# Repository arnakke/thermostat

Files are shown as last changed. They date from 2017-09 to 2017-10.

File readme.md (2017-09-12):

Intelligent Thermostat
----------------------
The thermostat should control room temperature based on the time of day and the location of residents. Thermostats will be connected together in rooms and homes, so if a room has multiple radiators, they will all have the same temperature set point, and if all residents have left the home, the temperature in all rooms will be lowered. Whether residents are home will be determined based on the location of their smartphones. 
Rooms should be able to have different temperatures during day and night, so that eg. the temperature is lowered in the living room during night and in the bedroom during day.  
The goal is a “set and forget” device, meaning that ideally you will never have to touch the app or the thermostats after initial configuration. That means it should also include air out detection, to stop heating when windows or doors are open. This detection could be augmented by utilizing outdoor temperature measurements from an online weather service.  
The device might also include a photovoltaic cell (or alternatively a peltier element) to reduce or eliminate battery changes.  
The design philosophy is to have as simple a user experience as possible. The thermostat should be easily installable and simple to configure, with no central control unit.

While there are a lot of similar products in the market, this thermostat sets itself apart by having:
* Centralized control without a central control unit
* Potentially a much lower price point than comparable systems (low price bill of materials)
* A design goal of being simple, unintrusive and “set and forget” (in contrast to big control panels, painful programming, manually turning on/off remotely and similar features)
* Open software and hardware design

### Preliminary requirements:
1. Thermostat unit should be mountable on Danfoss type  RA radiator valve
2. Thermostat unit should be able to partially open the radiator valve in at least 20 steps
3. Thermostat unit should be able to completely close the radiator valve
4. Thermostat unit should be able to measure temperature in a resolution of 0.1 °C with +/- 0.5 °C precision in the range 0 - 30 °C
5. Thermostat unit should be able to regulate the temperature to within +/- 0.5 °C of the set point, measured as a 5 minute average (doors and windows closed, moderate ventilation)
6. Thermostat unit should have a battery life of minimum 6 months
7. Thermostat units communicate over wifi
8. The control app should be able to run on Android 4.4
9. Residents should be warned of low battery in a thermostat unit through the control app
10. Temperature can be set per room in the control app, with different settings for night and day
11. The hours for day and night can be configured in the control app
12. The time should be set automatically in the thermostat unit
13. Changing the temperature in a room changes the set point of all units belonging to that room
14. Changing the temperature in a room should take effect on all thermostat units after max. 5 minutes
15. When all registered resident smartphones are away from the home, the temperature is lowered in all rooms relatively to the distance to the nearest resident (beeline)
16. The temperature set point will never go below 5 °C
17. A registered resident smartphone that doesn’t report its position should be considered to approach the home at a configurable speed with default 50 km/h
18. Thermostat units should be able to detect an open window based on change in temperature, possibly taking into consideration outdoor temperature (to be specified further)

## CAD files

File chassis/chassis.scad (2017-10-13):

/*
 * chassis.scad - Thermostat chassis drawings for laser cutting
 * 
 * Copyright 2017 Marcel Clausen
 * 
 * This program is free software: you can redistribute it and/or modify
 * it under the terms of the GNU General Public License as published by
 * the Free Software Foundation, either version 3 of the License, or
 * (at your option) any later version.
 *
 * This program is distributed in the hope that it will be useful,
 * but WITHOUT ANY WARRANTY; without even the implied warranty of
 * MERCHANTABILITY or FITNESS FOR A PARTICULAR PURPOSE.  See the
 * GNU General Public License for more details.
 *
 * You should have received a copy of the GNU General Public License
 * along with this program.  If not, see <http://www.gnu.org/licenses/>.
 *
 */

// 2D rendering module separation
module_spacing = 3;

// Material
thickness = 3;

// Chassis outer dimensions
boxw = 40;
boxh = 54;
boxl = 70;

// Threaded rod (or machine screws) used for assembly
join_rod_r = 3 / 2;

// Target minimum size for finger joints
min_joint_width = 7;

// Offset of valve mount hole relative to box vertical center
hole_y_offset = 7;

// Lever dimensions
lever_length = 24;
lever_ratio = 3;
lever_width = 6;
lever_axis_rod_r = 3/2;

// Measurements of Danfoss RA radiator valve
RA_valve_radius = 22.8 / 2;
RA_valve_radius_outer = 20 / 2;
RA_valve_radius_dents_bottom = 21 / 2;
RA_valve_dents_width = 4.25;
RA_valve_dents_shape_r = 2.96;
RA_valve_dents_length = RA_valve_radius - RA_valve_radius_dents_bottom;
RA_valve_dents_center_pos = RA_valve_radius + RA_valve_dents_shape_r -
	RA_valve_dents_length;
RA_valve_back_to_tip = 32.6;

// Measurements of geared micro motor
motorw = 12;
motorh = 10;
motorl = 24.3;
motor_front_hole_r = 4/2;
motor_rear_hole_r = 5/2;
motor_wire_holes_r = 3/2;
motor_wire_holes_x_center_offset = 3.5;
motor_shaft_r = 2.9;


/*
 * Add finger joints to a side (or holes for inserting fingers into).
 * The shapes produced should be subtracted.
 */
module joints(side_length, vertical, gender, thickness=thickness,
			  min_joint_width=min_joint_width) {
	// Male joints will cut off the cornes, so the available length
	// for fingers is (in case of adjacent male joints)
	run_length = side_length - thickness * 2;

	// Distance from end (corner - thickness) to first finger, relative to
	// finger width
	end_space_scale = 0.8;

	calc_length = run_length - end_space_scale * 2 * min_joint_width;
	num = floor((calc_length / min_joint_width + 1) / 2);
	finger_width = run_length / (2 * num - 1 + 2 * end_space_scale);
	x_offset = -(num - 1) * finger_width;

	rotate(vertical ? 90 : 0) {
		difference() {
			if (gender == "male")
				square([side_length, thickness], true);
			for (n = [0 : num - 1]) {
				translate([x_offset + n * finger_width * 2, 0]) {
					square([finger_width, thickness], true);
				}
			}
		}
	}
}

/*
 * Square with finger joints.
 */
module jointed_square(width, height, vert_gender, horiz_gender) {
	difference() {
		square([width, height], true);

		translate([0, (height - thickness) / 2])
			joints(width, false, horiz_gender);
		translate([0, -(height - thickness) / 2])
			joints(width, false, horiz_gender);
		translate([(width - thickness) / 2, 0])
			joints(height, true, vert_gender);
		translate([-(width - thickness) / 2, 0])
			joints(height, true, vert_gender);
	}
}

// Shape of RA type valve, center at [0,0]
module ra_valve_hole() {
	difference() {
		circle(r=RA_valve_radius, $fn=120);

		// Dents
		for (n = [0 : 11]) {
			translate([cos(n / 12 * 360) * RA_valve_dents_center_pos,
						  sin(n / 12 * 360) * RA_valve_dents_center_pos]
					   ) {
				circle(r=RA_valve_dents_shape_r, $fn=40);
			}
		}
	}
}

// Holes for joining the layers with a threaded rod
module join_holes() {
	num_holes = 4;
	center_dist = RA_valve_radius + 3 + join_rod_r;
	angle = 360 / num_holes / 2;

	for (n = [0 : num_holes - 1]) {
			translate([cos(n / num_holes * 360 + angle) * center_dist,
						  sin(n / num_holes * 360 + angle) * center_dist]
					   ) {
				circle(r=join_rod_r, $fn=40);
			}
	}
}

// Common shape of rear assembly layers
module rear_common(cut_vertical) {
	difference() {
		translate([0, -hole_y_offset]) {
			difference() {
				jointed_square(boxw, boxh, "male", "male");
				// Cut notches at vertical or horiz edges
				if (cut_vertical) {
					translate([-(boxw - thickness) / 2, 0])
						square([thickness, boxh], true);
					translate([(boxw - thickness) / 2, 0])
						square([thickness, boxh], true);
				} else {
					translate([0, (boxh - thickness) / 2])
						square([boxw, thickness], true);
					translate([0, -(boxh - thickness) / 2])
						square([boxw, thickness], true);
				}
			}
		}
		join_holes();
	}
}

module rear_asm_1_3() {
	difference() {
		rear_common(false);
		ra_valve_hole();
	}
}

module rear_asm_2() {
	difference() {
		rear_common(true);
		ra_valve_hole();
	}
}

module rear_asm_4() {
	difference() {
		rear_common(true);
		// Center hole
		circle(r=RA_valve_radius_outer);
		// Screw holes
		square([boxw, thickness], true);
	}
}

module rear_asm_5() {
	difference() {
		rear_common(false);
		// Center hole
		circle(r=RA_valve_radius_outer);
	}
}

module sides() {
	difference() {
		jointed_square(boxl, boxh, "female", "female");
		// Notches for rear assembly layers
		translate([-boxl / 2 + 2.5 * thickness, 0])
			joints(boxh, true, "female");
		translate([-boxl / 2 + 4.5 * thickness, 0])
			joints(boxh, true, "female");
		// Holes for lever axis rod
		translate([-boxl / 2 + RA_valve_back_to_tip,
					  hole_y_offset - lever_length / (lever_ratio + 1)])
			circle(r=lever_axis_rod_r, $fn=40);
	}
}

module top_bottom() {
	difference() {
		union() {
			jointed_square(boxl, boxw, "female", "male");
			// Undo left notches
			translate([-boxl / 2 + 0.5 * thickness, 0])
				square([thickness, boxw - 2 * thickness], true);
		}
		// Notches for rear assembly layers
		translate([-boxl / 2 + 1.5 * thickness, 0])
			joints(boxw, true, "female");
		translate([-boxl / 2 + 3.5 * thickness, 0])
			joints(boxw, true, "female");
	}
}

module front() {
	jointed_square(boxw, boxh, "male", "male");
}

module lever_sides() {
	difference() {
		union() {
			square([lever_width, lever_length], true);
			// Add rounded ends (extending length)
			translate([0, lever_length / 2])
				circle(d=lever_width, $fn=40);
			translate([0, -lever_length / 2])
				circle(d=lever_width, $fn=40);
		}
		// Hole for axis rod
		translate([0, lever_length * (lever_ratio / (lever_ratio + 1) - 1/2)])
			circle(r=lever_axis_rod_r, $fn=40);
		// Holes for join rods
		translate([0, lever_length / 2 - join_rod_r / 4])
			circle(r=join_rod_r, $fn=40);
		translate([0, - lever_length / 2 + lever_width / 2 + 3 * join_rod_r])
			circle(r=join_rod_r, $fn=40);
	}
}

module lever_middle() {
	difference() {
		lever_sides();
		translate([0, -lever_length / 2])
			square([lever_width, lever_width], true);
	}
}

// Helper for aligning modules
module row(x, y, width, module_spacing=module_spacing) {
	for (i = [0 : $children - 1]) {
		translate([x + (width + module_spacing) * i, y])
			children(i);
	}
}

// Render the modules
row(boxw / 2, boxh / 2 + hole_y_offset, boxw) {
	rear_asm_1_3();
	rear_asm_2();
	rear_asm_1_3();
	rear_asm_4();
	rear_asm_5();
}

row(boxl / 2, 1.5 * boxh + module_spacing, boxl) {
	sides();
	sides();
	top_bottom();
	top_bottom();
}

row(lever_width / 2, 2 * boxh + 2 * module_spacing + (lever_length + lever_width) / 2, lever_width) {
	lever_sides();
	lever_sides();
	lever_middle();
}

row(boxw / 2, 2 * boxh + 3 * module_spacing + (lever_length + lever_width) + boxh / 2, boxw) { 
	front();
}

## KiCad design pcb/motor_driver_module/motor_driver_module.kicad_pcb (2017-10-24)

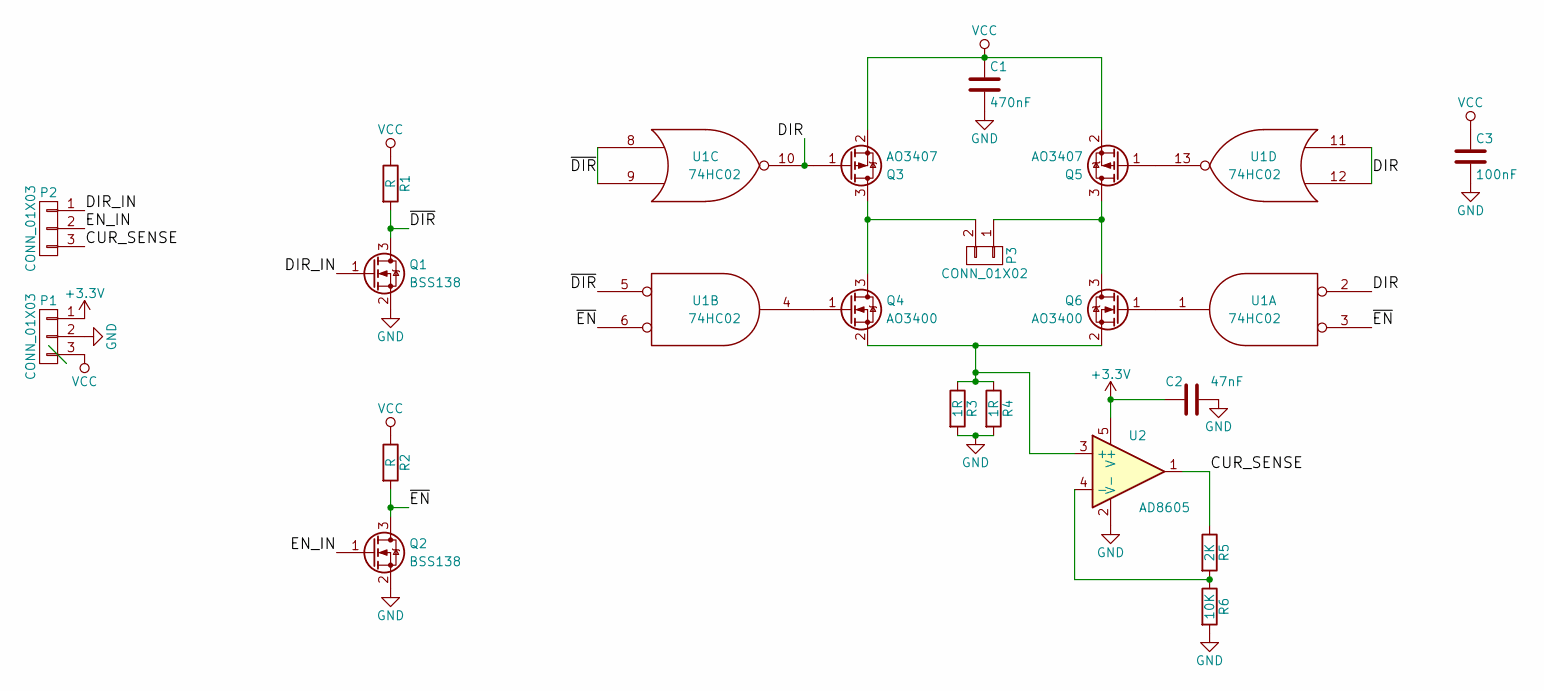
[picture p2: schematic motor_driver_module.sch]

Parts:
C1: 470nF; C_0805
C2: 47nF; C_0805
C3: 100nF; C_0805
P1, P2: CONN_01X03; Pin_Header_Straight_1x03
P3: CONN_01X02; Pin_Header_Straight_1x02
Q1, Q2: BSS138; SOT-23
Q3, Q5: AO3407; SOT-23
Q4, Q6: AO3400; SOT-23
R1, R2: R; R_0805
R3, R4: 1R; R_0805
R5: 2K; R_0805
R6: 10K; R_0805
U1: 74HC02; SOIC-14_3.9x8.7mm_Pitch1.27mm
U2: AD8605; SOT-23-5

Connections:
+3V3: C2.2, P1.1, U2.5 (V+)
/CUR_SENSE: P2.3, R5.1, U2.1
/DIR: U1.2, U1.11, U1.12
/DIR_IN: P2.1, Q1.1 (G)
/EN_IN: P2.2, Q2.1 (G)
/~DIR: Q1.3 (D), R1.2, U1.5, U1.8, U1.9
/~EN: Q2.3 (D), R2.2, U1.3, U1.6
GND: C1.2, C2.1, C3.2, P1.2, Q1.2 (S), Q2.2 (S), R3.2, R4.2, R6.2, U1.7 (GND), U2.2 (V-)
unnamed: P3.1, Q5.3 (D), Q6.3 (D)
unnamed: P3.2, Q3.3 (D), Q4.3 (D)
unnamed: Q3.1 (G), U1.10
unnamed: Q4.1 (G), U1.4
unnamed: Q4.2 (S), Q6.2 (S), R3.1, R4.1, U2.3 (+)
unnamed: Q5.1 (G), U1.13
unnamed: Q6.1 (G), U1.1
unnamed: R5.2, R6.1, U2.4 (-)
VCC: C1.1, C3.1, P1.3, Q3.2 (S), Q5.2 (S), R1.1, R2.1, U1.14 (VCC)

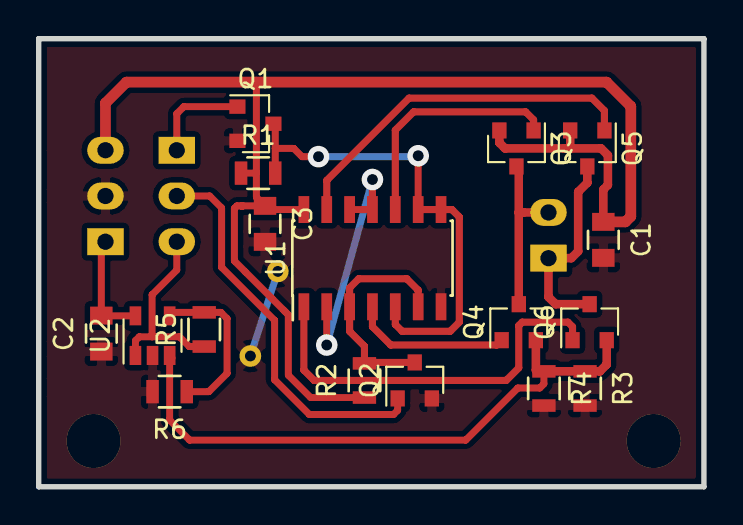
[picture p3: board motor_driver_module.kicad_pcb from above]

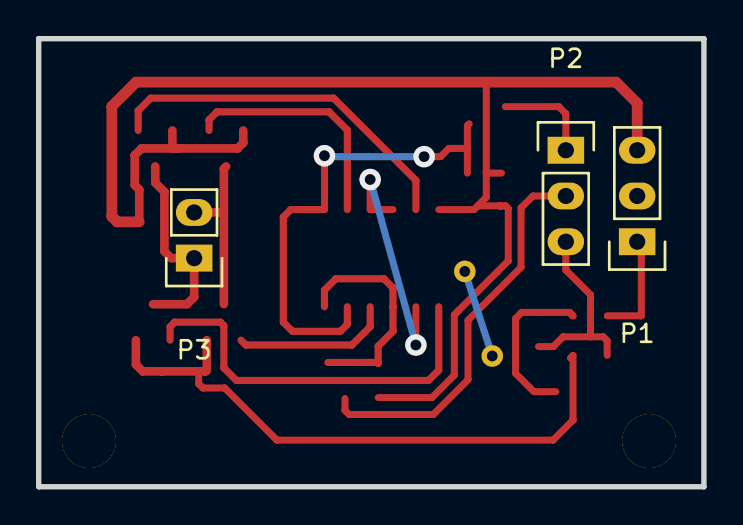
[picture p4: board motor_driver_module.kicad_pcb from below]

Board: 2 copper layers, 37.0 x 24.9 mm, 20 parts (3 on the bottom side), 17 nets.

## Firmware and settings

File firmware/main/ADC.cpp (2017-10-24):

/*
 * ADC.cpp - ESP32 ADC class implementation
 *
 * Copyright 2017 Marcel Clausen
 *
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
 */

#include "ADC.hpp"


// Static data members
float ADC::offset = 0.09;
float ADC::vref = 1.1;


ADC::ADC(adc1_channel_t channel) :
	channel(channel)
{
	adc1_config_width(ADC_WIDTH_12Bit);
	adc1_config_channel_atten(channel, ADC_ATTEN_0db);
}


int ADC::read_raw()
{
	return adc1_get_raw(channel);
}


float ADC::read_voltage()
{
	return to_voltage(read_raw());
}


float ADC::read_voltage_avg(int n)
{
	int result = 0;
	for (int i = 0; i < n; i++) {
		result += read_raw();
	}
	return to_voltage(result / n);
}


float ADC::to_voltage(int raw)
{
	return raw / 4096.0f * (vref - offset) + offset;
}

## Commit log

2017-10-13 Initial chassis design
    [chassis.scad]
2017-10-24 Added motor driver PCB prototype
    [motor_driver_module.kicad_pcb, motor_driver_module.sch]
2017-10-24 Added ADC class
2017-10-24 Added temperature sensor class
